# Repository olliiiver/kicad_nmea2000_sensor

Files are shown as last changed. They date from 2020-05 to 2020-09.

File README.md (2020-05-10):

# NMEA 2000 KiCAD PCB and sketch for analog inputs (e.g. water level, fuel gauge, switch, etc ...)

Based on https://github.com/ttlappalainen/NMEA2000

Can be used to create a NMEA 2000 device like a sensor for fuel gauges. The board is easy to work with since it contains ISP and serial ports. 

*Use at your own risk. Don't forget the right external fuses, etc.* 

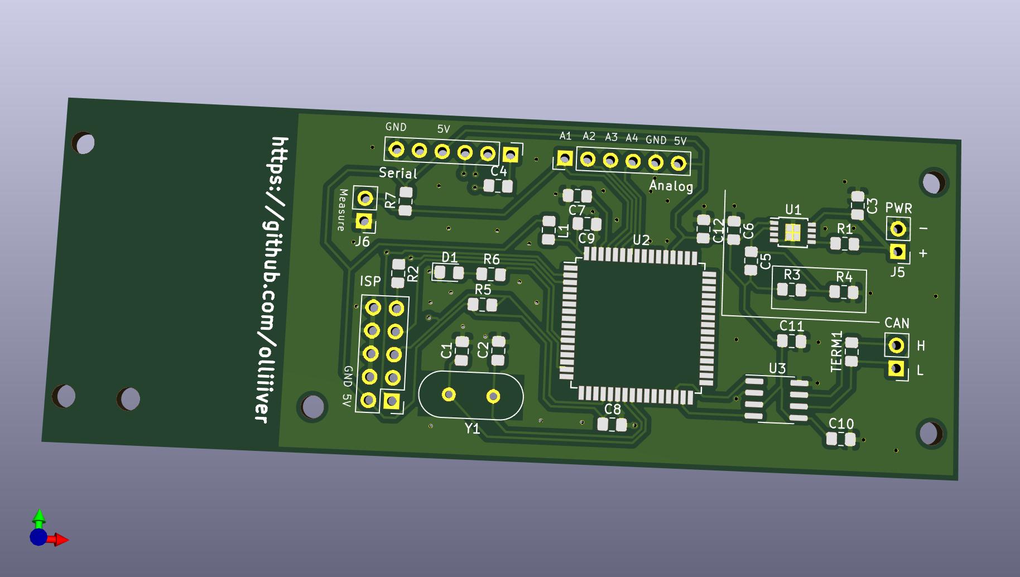
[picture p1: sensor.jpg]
RENDERED


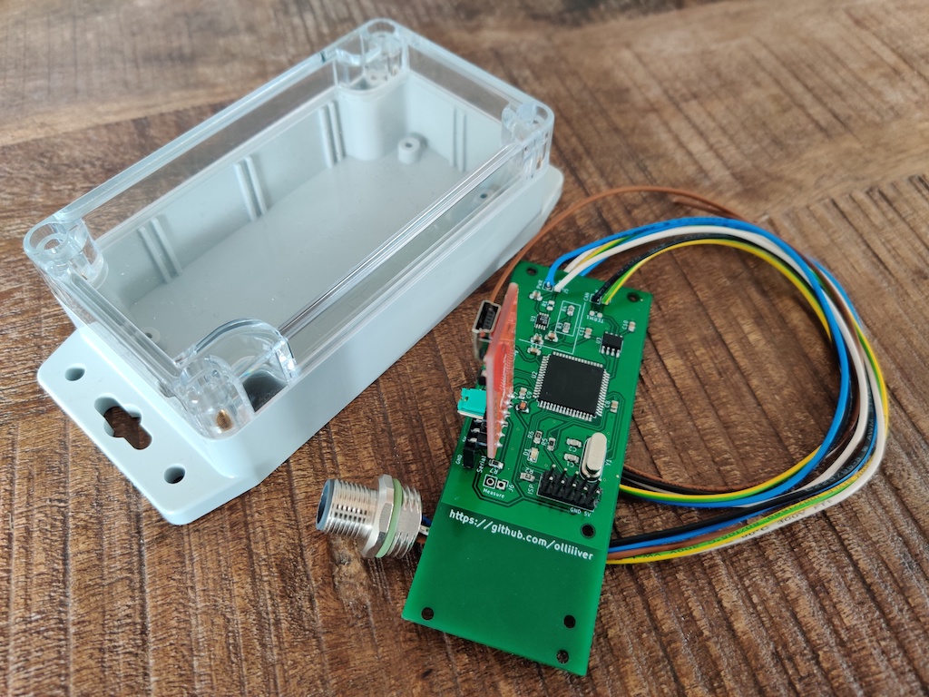
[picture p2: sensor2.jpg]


## Prerequisites

- A NMEA2000 or Seatalk NG network
- PlatformIO CLI from https://platformio.org
- A PCB manufacturer of your choice and some SMD soldering experience 

## How to

### PCB

Equip SMD parts for power (LDO, etc) first and measure input to output voltage carefully. Adjust R4 (and R3) resistors, if necessary. If voltage is around 4.8V - 5V, place other parts. 

### Burn bootloader

0. Disconnect PCB from other power sources or adapters.
1. Connect an AVR ISP programmer (usbasp) to ISP port
2. Change into arduino-blink directory and type ```pio run --target fuses```. If the chip doesn't answer run avrdude manually with ```-B``` flag to set the bit clock rate, see  https://electronics.stackexchange.com/questions/388324/avrdude-error-program-enable-target-doesnt-answer-1
3. Change into arduino-blink directory and type ```pio run --target bootloader```
4. Optional: The sketch can be uploaded via ISP directly from arduino-sensor directory (```pio run --target program```)

### Upload sketch

0. Disconnect PCB from other power sources or adapters.
1. Connect an USB serial adapter to serial port
2. Change into arduino-sensor directory
3. Run ```pio run --target upload```

If errors appear during upload (e.g. ```programmer is out of sync``` or ```protocol error``` use another USB cable, USB hub or USB adapter. Check USB voltage (>4.89V) and ripple noise.

## BOM

- Case: RND 455-00182 
  https://www.reichelt.de/kunststoffgehaeuse-115-x-65-x-40-mm-ip65-rnd-455-00182-p193396.html
  https://www.distrelec.de/Web/Downloads/_t/ds/RND_455-00182_30064403_mcd_eng_tds.pdf

- AVR: AT90CAN128
  https://www.reichelt.de/atmel-ic-at-90can128-p55544.html

- Transceiver: MCP 2562-E/SN
  https://www.reichelt.de/bus-controller-1-treiber-1-empfaenger-so-8-mcp-2562-e-sn-p143745.html

- Connector: M12 Plug
  https://www.reichelt.de/sal-m12x1-5-pol-einbaustecker-sal12-fs50-p136981.html?&trstct=pol_38&nbc=1

- 12V to 5V: LDO 
 https://cdn-reichelt.de/documents/datenblatt/A200/LT3010EMS8E5.pdf

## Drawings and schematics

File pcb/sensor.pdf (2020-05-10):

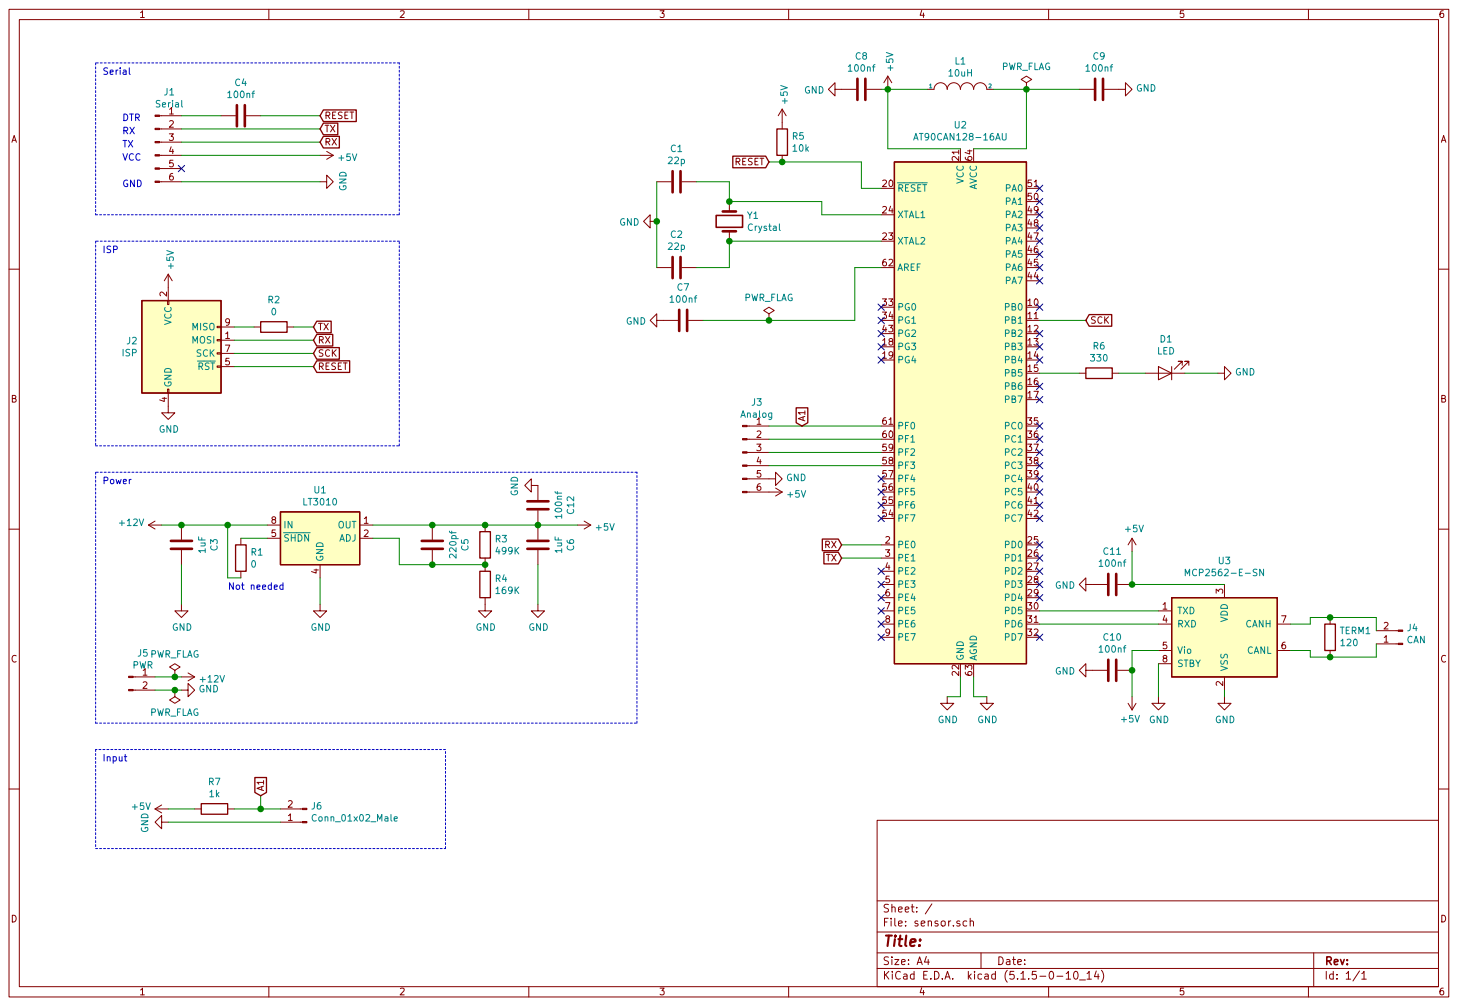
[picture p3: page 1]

Id: 1/1 Title: File: sensor.sch Sheet: /

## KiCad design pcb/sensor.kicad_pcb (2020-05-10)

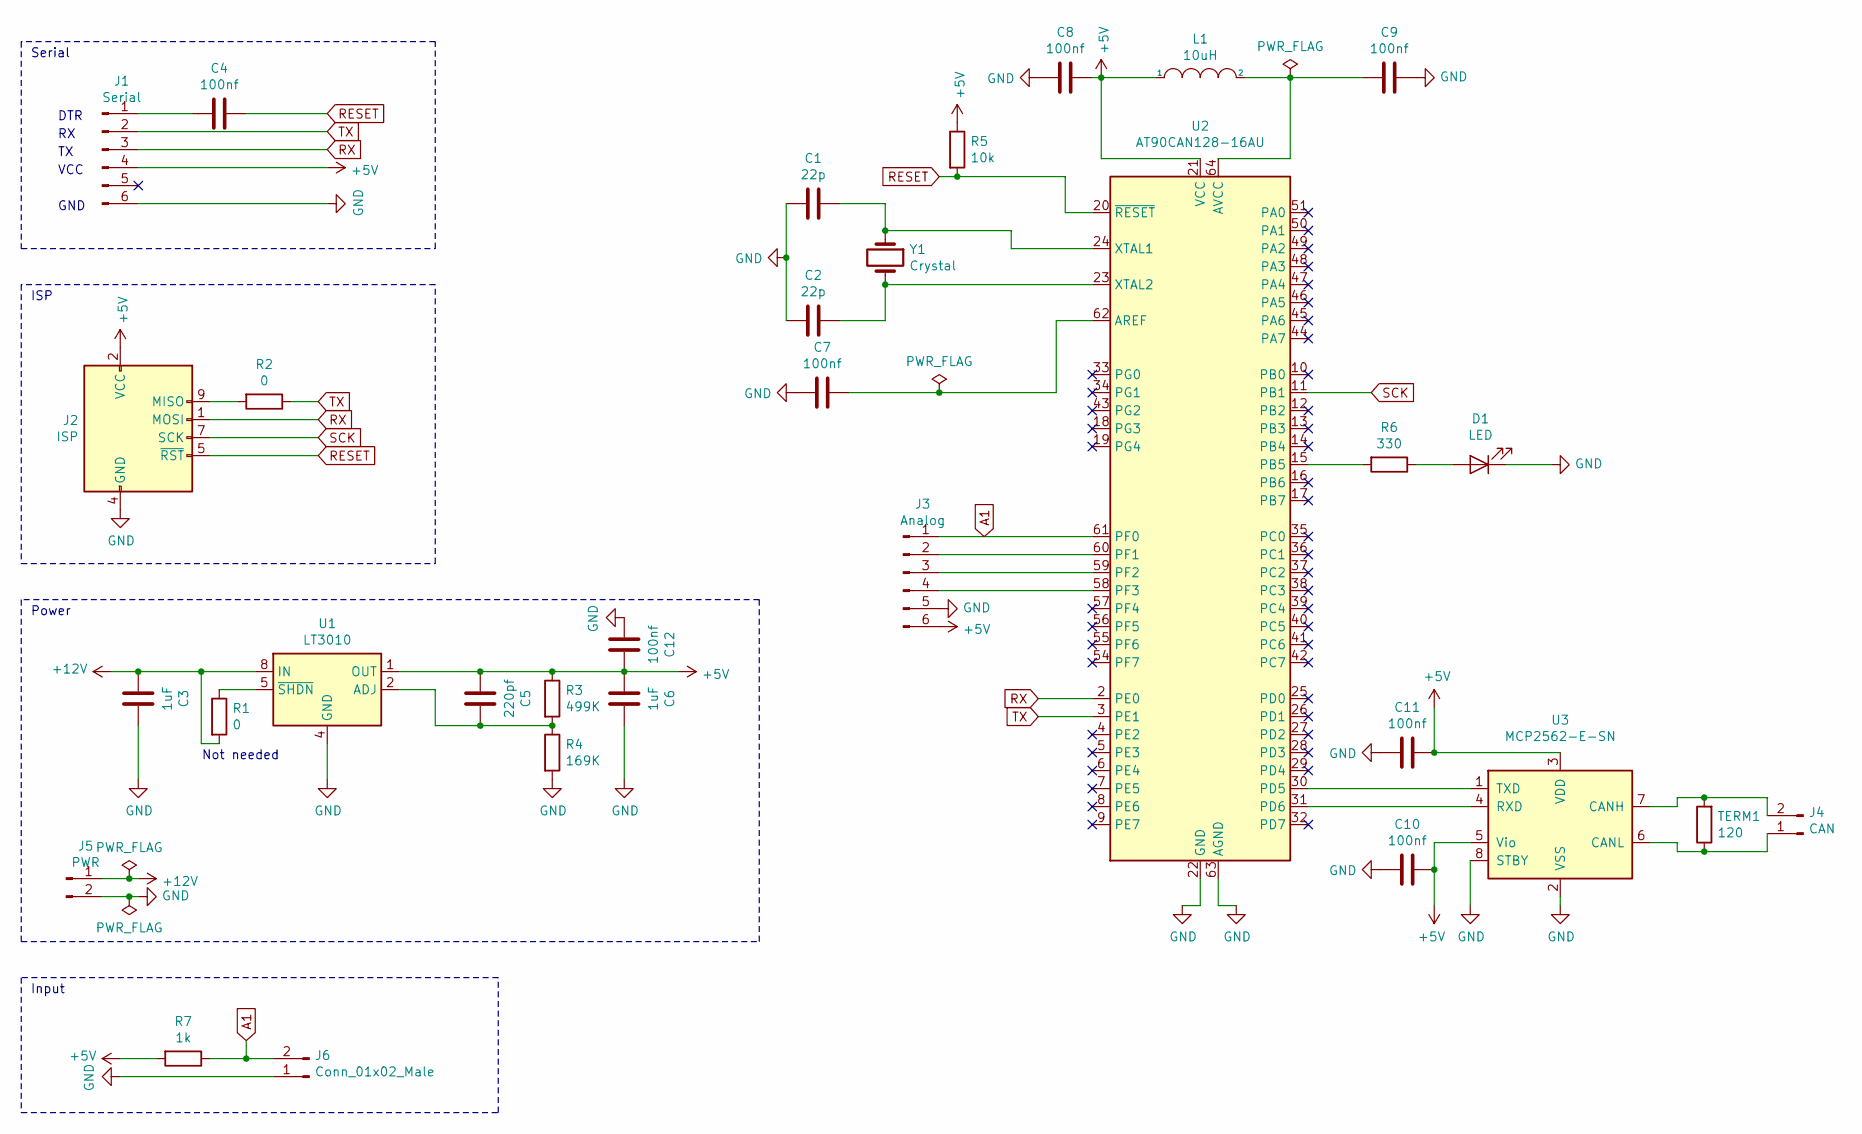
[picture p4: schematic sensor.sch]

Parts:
C1, C2: 22p; C_0805_2012Metric_Pad1.15x1.40mm_HandSolder
C3, C6: 1uF; C_0805_2012Metric_Pad1.15x1.40mm_HandSolder
C4, C7, C8, C9, C10, C11, C12: 100nf; C_0805_2012Metric_Pad1.15x1.40mm_HandSolder
C5: 220pf; C_0805_2012Metric_Pad1.15x1.40mm_HandSolder
D1: LED; LED_0805_2012Metric_Pad1.15x1.40mm_HandSolder
J1: Serial; PinHeader_1x06_P2.54mm_Vertical
J2: ISP; PinHeader_2x05_P2.54mm_Vertical
J3: Analog; PinHeader_1x06_P2.54mm_Vertical
J4: CAN; PinHeader_1x02_P2.54mm_Vertical
J5: PWR; PinHeader_1x02_P2.54mm_Vertical
J6: Conn_01x02_Male; PinHeader_1x02_P2.54mm_Vertical
L1: 10uH; L_0805_2012Metric_Pad1.15x1.40mm_HandSolder
R1, R2: 0; R_0805_2012Metric_Pad1.15x1.40mm_HandSolder
R3: 499K; R_0805_2012Metric_Pad1.15x1.40mm_HandSolder
R4: 169K; R_0805_2012Metric_Pad1.15x1.40mm_HandSolder
R5: 10k; R_0805_2012Metric_Pad1.15x1.40mm_HandSolder
R6: 330; R_0805_2012Metric_Pad1.15x1.40mm_HandSolder
R7: 1k; R_0805_2012Metric_Pad1.15x1.40mm_HandSolder
TERM1: 120; R_0805_2012Metric_Pad1.15x1.40mm_HandSolder
U1: LT3010; MSOP-8-1EP_3x3mm_P0.65mm_EP1.68x1.88mm
U2: AT90CAN128-16AU; TQFP-64_14x14mm_P0.8mm
U3: MCP2562-E-SN; SOIC-8_3.9x4.9mm_P1.27mm
Y1: Crystal; Crystal_HC49-4H_Vertical

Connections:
+5V: C5.2, C6.2, C8.1, C10.1, C11.1, C12.1, J1.4, J2.2 (VCC), J3.6, L1.1, R3.1, R5.1, R7.2, U1.1 (OUT), U2.21 (VCC), U2.52 (VCC), U3.3 (VDD), U3.5 (Vio)
+12V: C3.2, J5.1, R1.2, U1.8 (IN)
A1: J3.1, J6.2, R7.1, U2.61 (PF0)
GND: C1.2, C2.2, C3.1, C6.1, C7.2, C8.2, C9.1, C10.2, C11.2, C12.2, D1.1 (K), J1.6, J2.4 (GND), J2.6 (GND), J2.8 (GND), J2.10 (GND), J3.5, J5.2, J6.1, R4.2, U1.4 (GND), U1.9 (GND), U2.22 (GND), U2.53 (GND), U2.63 (AGND), U3.2 (VSS), U3.8 (STBY)
unnamed: C1.1, U2.24 (XTAL1), Y1.1
unnamed: C2.1, U2.23 (XTAL2), Y1.2
unnamed: C4.2, J1.1
unnamed: C5.1, R3.2, R4.1, U1.2 (ADJ)
unnamed: C7.1, U2.62 (AREF)
unnamed: C9.2, L1.2, U2.64 (AVCC)
unnamed: D1.2 (A), R6.1
unnamed: J2.9 (MISO), R2.2
unnamed: J3.2, U2.60 (PF1)
unnamed: J3.3, U2.59 (PF2)
unnamed: J3.4, U2.58 (PF3)
unnamed: J4.1, TERM1.1, U3.6 (CANL)
unnamed: J4.2, TERM1.2, U3.7 (CANH)
unnamed: R1.1, U1.5 (~SHDN)
unnamed: R6.2, U2.15 (PB5)
unnamed: U2.30 (PD5), U3.1 (TXD)
unnamed: U2.31 (PD6), U3.4 (RXD)
RESET: C4.1, J2.5 (~RST), R5.2, U2.20 (~RESET)
RX: J1.3, J2.1 (MOSI), U2.2 (PE0)
SCK: J2.7 (SCK), U2.11 (PB1)
TX: J1.2, R2.1, U2.3 (PE1)

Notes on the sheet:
Serial
ISP
Power
Input
DTR
VCC
GND
Not needed

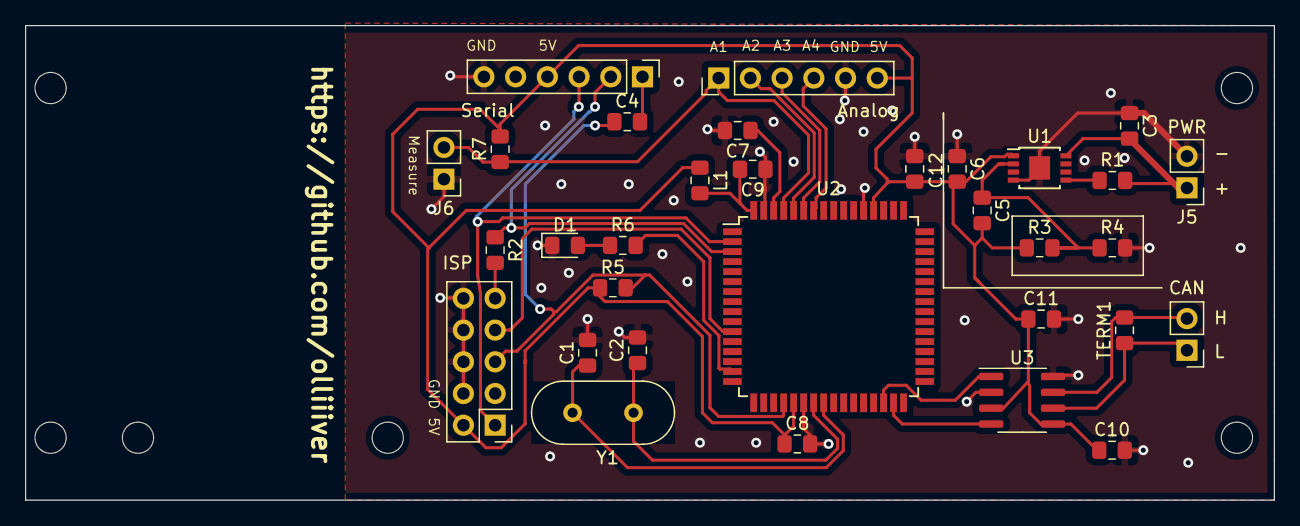
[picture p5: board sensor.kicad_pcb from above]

Board: 2 copper layers, 100.0 x 38.0 mm, 32 parts (0 on the bottom side), 25 nets.

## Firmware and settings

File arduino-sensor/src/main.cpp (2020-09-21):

#include <Arduino.h>

#include <N2kMsg.h>
#include <NMEA2000.h>
#include <avr_can.h>            // https://github.com/thomasonw/avr_can
#include <NMEA2000_avr.h>       // https://github.com/thomasonw/NMEA2000_avr


#include <N2kMessages.h>

tNMEA2000_avr NMEA2000;

Stream *OutputStream;

// List here messages your device will transmit.
const unsigned long TransmitMessages[] PROGMEM={127505L,0};

int count = 0;

void setup() {

  pinMode(LED_BUILTIN, OUTPUT);

  // Set Product information
  //NMEA2000.SetN2kCANSendFrameBufSize(50);
  //NMEA2000.SetN2kCANReceiveFrameBufSize(2);
  NMEA2000.SetN2kCANMsgBufSize(1);

  NMEA2000.SetProductInformation("00001337", // Manufacturer's Model serial code
                                 100, // Manufacturer's product code
                                 "Message sender example",  // Manufacturer's Model ID
                                 "1.0.0.15 (2017-01-01)",  // Manufacturer's Software version code
                                 "1.0.0.0 (2017-01-01)" // Manufacturer's Model version
                                 );
  // Set device information
  NMEA2000.SetDeviceInformation(1337, // Unique number. Use e.g. Serial number.
                                132, // Device function=Analog to NMEA 2000 Gateway. See codes on http://www.nmea.org/Assets/20120726%20nmea%202000%20class%20&%20function%20codes%20v%202.00.pdf
                                25, // Device class=Inter/Intranetwork Device. See codes on  http://www.nmea.org/Assets/20120726%20nmea%202000%20class%20&%20function%20codes%20v%202.00.pdf
                                2046 // Just choosen free from code list on http://www.nmea.org/Assets/20121020%20nmea%202000%20registration%20list.pdf
                               );

  Serial.begin(115200);
  OutputStream=&Serial;

  // logging
  // NMEA2000.SetForwardStream(&Serial);  // PC output on due programming port
  // NMEA2000.SetForwardType(tNMEA2000::fwdt_Text); // Show in clear text. Leave uncommented for default Actisense format.
  // NMEA2000.SetForwardOwnMessages();

  // If you also want to see all traffic on the bus use N2km_ListenAndNode instead of N2km_NodeOnly below
  NMEA2000.SetMode(tNMEA2000::N2km_NodeOnly,22);

  // NMEA2000.EnableForward(false); // Disable all msg forwarding to USB (=Serial)
  NMEA2000.ExtendTransmitMessages(TransmitMessages);
  NMEA2000.Open();

  digitalWrite(LED_BUILTIN, HIGH);
  delay(150);
  digitalWrite(LED_BUILTIN, LOW);
}

#define SlowDataUpdatePeriod 1000

void SendN2kSlowData() {
  static unsigned long SlowDataUpdated=millis();
  tN2kMsg N2kMsg;

  int raw = 0;
  int percent = 0;
  float R1 = 1000; // known 1k
  float max = 160; // max sensor range (0 - 190 ohm)

  if (SlowDataUpdated+SlowDataUpdatePeriod<millis()) {
    SlowDataUpdated=millis();
    raw = analogRead(0);
    // percent = 100 - (raw / R1 * 100);
    //    percent = (raw / max * 100);
    if (raw < 15) {
      percent = 0;
    } else if (raw >= 15 && raw < 32) {
      percent = 10;
    } else if (raw >= 32 && raw < 50) {
      percent = 15;
    } else if (raw >= 50 && raw < 60) {
      percent = 20;
    } else if (raw >= 60 && raw < 70) {
      percent = 25;
    } else if (raw >= 70 && raw < 80) {
      percent = 30;
    } else if (raw >= 80 && raw < 105) {
      percent = 40;
    } else if (raw >= 105 && raw < 130) {
      percent = 50;
    } else if (raw >= 130 && raw < 155) {
      percent = 75;
    } else if (raw >= 155) {
      percent = 100;
    }


    percent = (percent > 100) ? 100 : percent;
    percent = (percent < 1) ? 0 : percent;
    OutputStream->print("===> raw: ");
    OutputStream->print(raw);
    OutputStream->print(" percent: ");
    OutputStream->println(percent);

    // Send fuel level in percent for the 2nd fuel tank (60 liters max vol.)
    SetN2kFluidLevel(N2kMsg, 1, N2kft_Fuel, percent, 60);
    NMEA2000.SendMsg(N2kMsg);

    if (count == 0) {
      digitalWrite(LED_BUILTIN, HIGH);
      count = 1;
    } else {
      digitalWrite(LED_BUILTIN, LOW);
      count = 0;
    }
  }


}

void loop() {
  SendN2kSlowData();
  NMEA2000.ParseMessages();
}

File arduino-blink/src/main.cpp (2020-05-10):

/**
 * Blink
 *
 * Turns on an LED on for one second,
 * then off for one second, repeatedly.
 */
#include "Arduino.h"

#ifndef LED_BUILTIN
#define LED_BUILTIN 13
#endif

void setup()
{
  // initialize LED digital pin as an output.
  pinMode(LED_BUILTIN, OUTPUT);
}

void loop()
{

   // wait for a second
  delay(1000);

  // turn the LED on (HIGH is the voltage level)
  digitalWrite(LED_BUILTIN, HIGH);

  // wait for a second
  delay(1000);

  // turn the LED off by making the voltage LOW
  digitalWrite(LED_BUILTIN, LOW);

}
